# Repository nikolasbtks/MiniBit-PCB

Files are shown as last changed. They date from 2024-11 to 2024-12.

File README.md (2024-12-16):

# MiniBit-PCB

## Description

This project demonstrates a custom 2-layer PCB containing the ESP32-S3-Mini microcontroller. This board can be used for embedded development or IoT applications using multiple peripherals.

## Components

1. Microcontroller: ESP32-S3-Mini
   - 512 KB SRAM and 8 MB Flash
   - 240 MHz clock speed 
   
2. USB Connectivity:
   - USB Type-C for data and power 
   - USBLC6-2SC6 for ESD protection

3. Power Supply: AP2112K-3.3 
   - Voltage regulator for stable 3.3V output
  
4. Headers:
   - JTAG headers for debugging
   - GPIO, I2C, UART headers for external connections

## Disclaimer

This project is currently in **testing phase**. The provided documentation is shared for prototyping and learning purposes. If you choose to manufacture and use the board, please proceed with care, as it has not yet been fully validated.

## Schematic and PCB Design

The board was designed using KiCad. Files from the PCB design can be found in the **hardware** folder for board manufacture. This folder includes:

- PCB Schematic 
- PCB Layout
- Gerber files
- Assembly files

## How to Use

1. Power the board
   - Use a USB Type-C cable to power the board.
   
2. Microcontroller Programming:
   - Use Arduino IDE or any other platform to program the microcontroller.
   - Use a debugger with JTAG headers.

3. Peripheral Access
   - Use the GPIO, I2C and UART headers to connect peripherals.

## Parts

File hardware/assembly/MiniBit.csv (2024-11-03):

Reference | Value | Datasheet | Footprint | Qty | DNP
C1,C3,C4 | 0.1μF | ~ | Capacitor_SMD:C_0402_1005Metric | 3
C2 | 22μF | ~ | Capacitor_SMD:C_0805_2012Metric | 1
C5,C6 | 1μF | ~ | Capacitor_SMD:C_0402_1005Metric | 2
C7,C8 | 10nF | ~ | Capacitor_SMD:C_0402_1005Metric | 2
D1 | Red LED | ~ | LED_SMD:LED_0603_1608Metric | 1
F1 | 500mA | ~ | Fuse:Fuse_0402_1005Metric | 1
J1,J2,J3,J4 | Conn_01x04_Pin | ~ | Connector_PinHeader_2.54mm:PinHeader_1x04_P2.54mm_Vertical | 4
J5 | USB_C_Receptacle_USB2.0_16P | https://www.usb.org/sites/default/files/documents/usb_type-c.zip | Connector_USB:USB_C_Receptacle_GCT_USB4105-xx-A_16P_TopMnt_Horizontal | 1
R1 | 10k | ~ | Resistor_SMD:R_0402_1005Metric | 1
R2 | 100R | ~ | Resistor_SMD:R_0603_1608Metric | 1
R3,R4 | 5.1k | ~ | Resistor_SMD:R_0402_1005Metric | 2
R5,R6 | 22R | ~ | Resistor_SMD:R_0603_1608Metric | 2
R7,R8 | 1k5 | ~ | Resistor_SMD:R_0603_1608Metric | 2
SW1,SW2 | SW_SPST | ~ | Button_Switch_SMD:SW_SPST_B3U-1000P | 2
U1 | ESP32-S3-MINI-1 | https://www.espressif.com/sites/default/files/documentation/esp32-s3-mini-1_mini-1u_datasheet_en.pdf | RF_Module:ESP32-S2-MINI-1 | 1
U2 | USBLC6-2SC6 | https://www.st.com/resource/en/datasheet/usblc6-2.pdf | Package_TO_SOT_SMD:SOT-23-6 | 1
U3 | AP2112K-3.3 | https://www.diodes.com/assets/Datasheets/AP2112.pdf | Package_TO_SOT_SMD:SOT-23-5 | 1

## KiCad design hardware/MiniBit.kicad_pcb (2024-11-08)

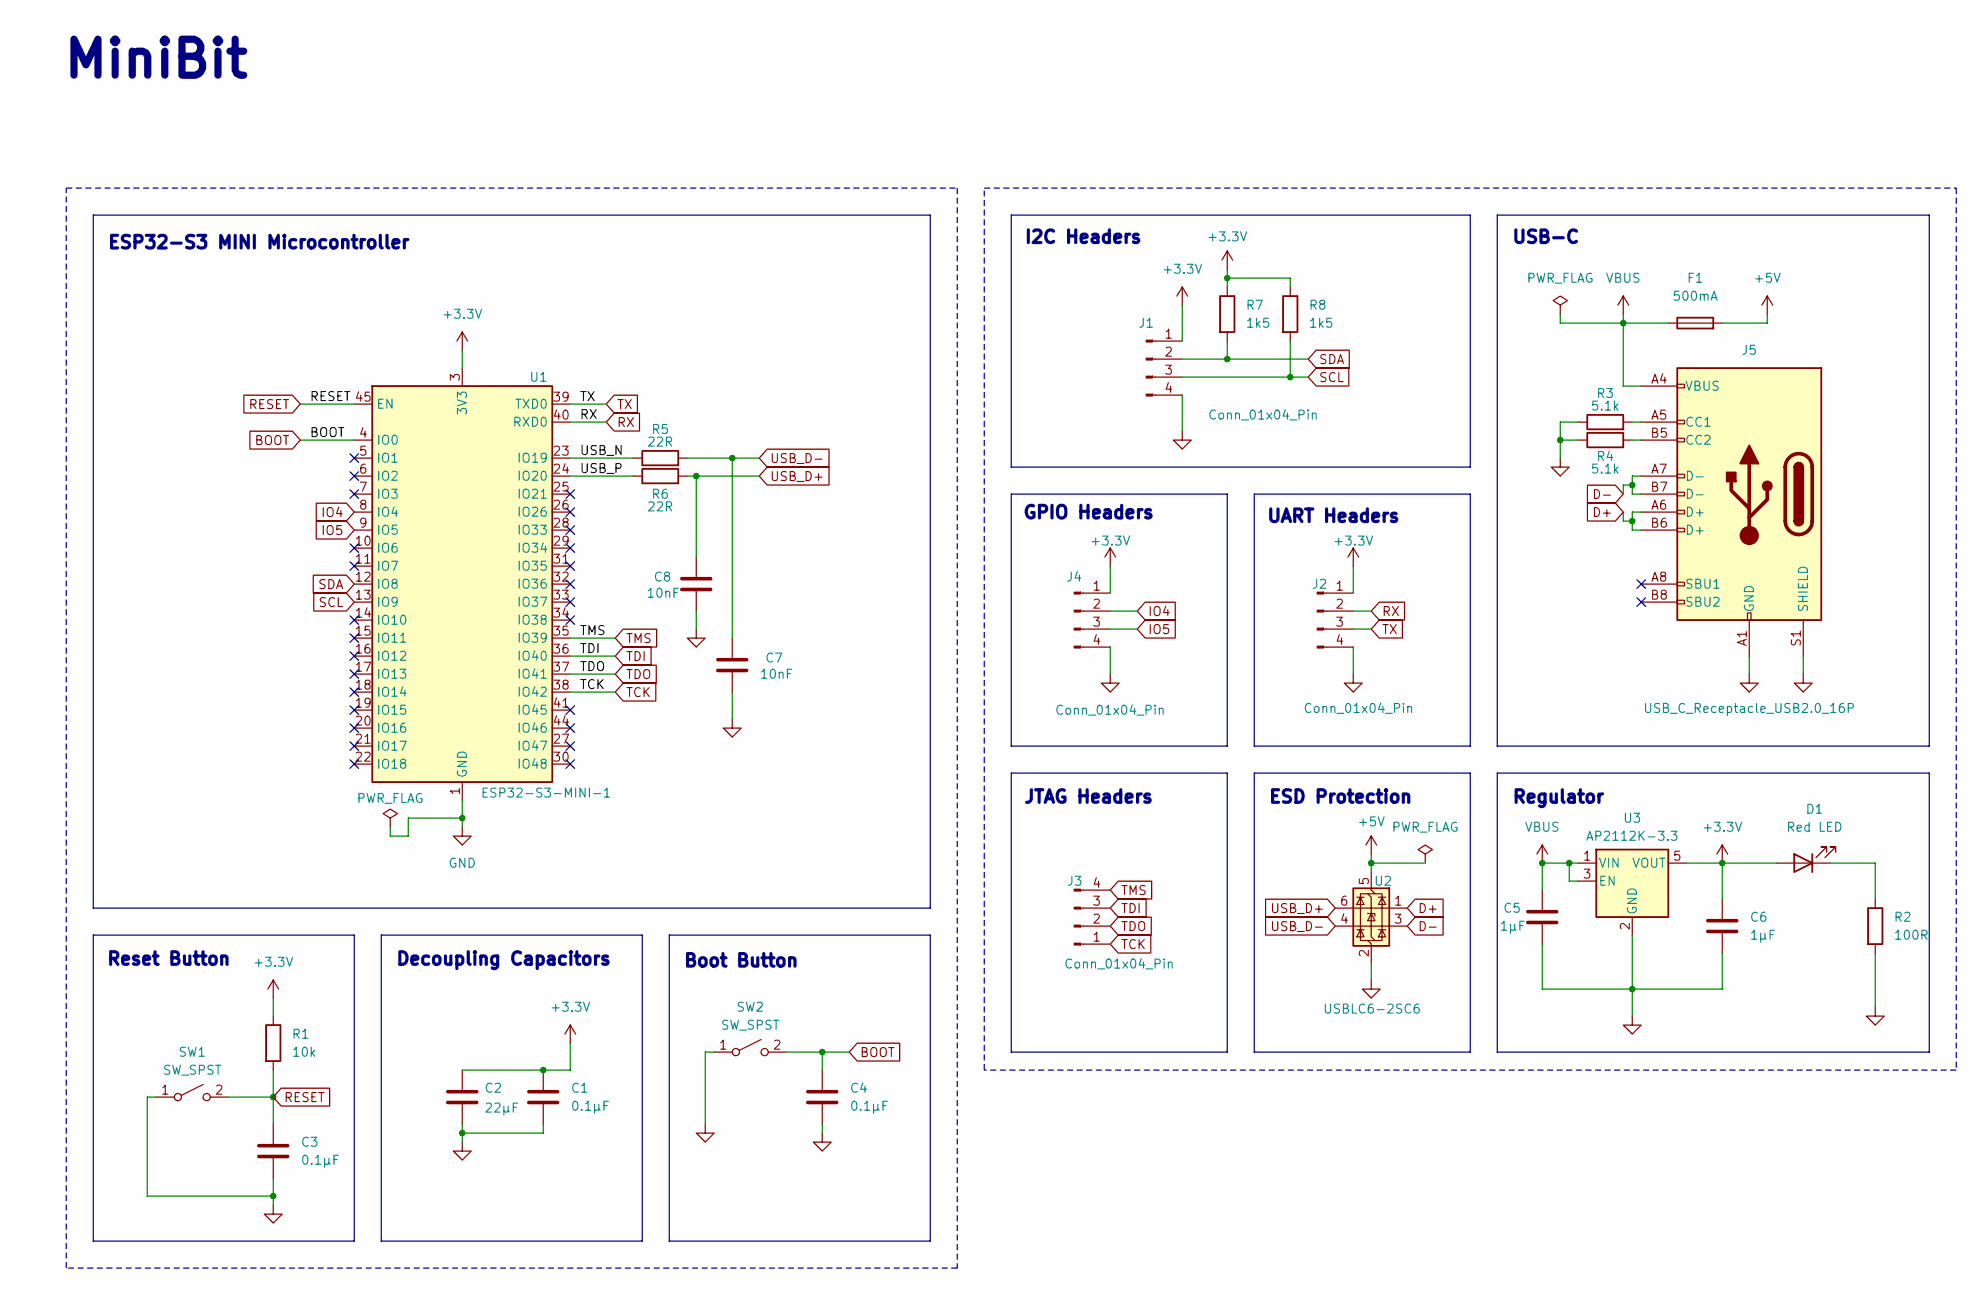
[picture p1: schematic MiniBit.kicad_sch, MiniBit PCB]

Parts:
C1, C3, C4: 0.1μF; C_0402_1005Metric
C2: 22μF; C_0805_2012Metric
C5, C6: 1μF; C_0402_1005Metric
C7, C8: 10nF; C_0402_1005Metric
D1: Red LED; LED_0603_1608Metric
F1: 500mA; Fuse_0402_1005Metric
J1, J2, J3, J4: Conn_01x04_Pin; PinHeader_1x04_P2.54mm_Vertical
J5: USB_C_Receptacle_USB2.0_16P; USB_C_Receptacle_GCT_USB4105-xx-A_16P_TopMnt_Horizontal
R1: 10k; R_0402_1005Metric
R2: 100R; R_0603_1608Metric
R3, R4: 5.1k; R_0402_1005Metric
R5, R6: 22R; R_0603_1608Metric
R7, R8: 1k5; R_0603_1608Metric
SW1, SW2: SW_SPST; SW_SPST_B3U-1000P
U1: ESP32-S3-MINI-1; ESP32-S2-MINI-1
U2: USBLC6-2SC6; SOT-23-6
U3: AP2112K-3.3; SOT-23-5

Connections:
+3.3V: C1.1, C2.1, C6.1, D1.2 (A), J1.1, J2.1, J4.1, R1.1, R7.1, R8.1, U1.3 (3V3), U3.5 (VOUT)
+5V: F1.2, U2.5 (VBUS)
/USB_N: R5.1, U1.23 (IO19)
/USB_P: R6.1, U1.24 (IO20)
BOOT: C4.1, SW2.2 (B), U1.4 (IO0)
D+: J5.A6 (D+), J5.B6 (D+), U2.1 (I/O1)
D-: J5.A7 (D-), J5.B7 (D-), U2.3 (I/O2)
GND: C1.2, C2.2, C3.2, C4.2, C5.2, C6.2, C7.2, C8.2, J1.4, J2.4, J4.4, J5.A1 (GND), J5.A12 (GND), J5.B1 (GND), J5.B12 (GND), J5.S1 (SHIELD), R2.2, R3.1, R4.1, SW1.1 (A), SW2.1 (A), U1.1 (GND), U1.2 (GND), U1.42 (GND), U1.43 (GND), U1.46 (GND), U1.47 (GND), U1.48 (GND), U1.49 (GND), U1.50 (GND), U1.51 (GND), U1.52 (GND), U1.53 (GND), U1.54 (GND), U1.55 (GND), U1.56 (GND), U1.57 (GND), U1.58 (GND), U1.59 (GND), U1.60 (GND), U1.61 (GND), U1.62 (GND), U1.63 (GND), U1.64 (GND), U1.65 (GND), U2.2 (GND), U3.2 (GND)
IO4: J4.2, U1.8 (IO4)
IO5: J4.3, U1.9 (IO5)
unnamed: D1.1 (K), R2.1
unnamed: J5.A5 (CC1), R3.2
unnamed: J5.B5 (CC2), R4.2
RESET: C3.1, R1.2, SW1.2 (B), U1.45 (EN)
RX: J2.2, U1.40 (RXD0)
SCL: J1.3, R8.2, U1.13 (IO9)
SDA: J1.2, R7.2, U1.12 (IO8)
TCK: J3.1, U1.38 (IO42)
TDI: J3.3, U1.36 (IO40)
TDO: J3.2, U1.37 (IO41)
TMS: J3.4, U1.35 (IO39)
TX: J2.3, U1.39 (TXD0)
USB_D+: C8.1, R6.2, U2.6 (I/O1)
USB_D-: C7.1, R5.2, U2.4 (I/O2)
VBUS: C5.1, F1.1, J5.A4 (VBUS), J5.A9 (VBUS), J5.B4 (VBUS), J5.B9 (VBUS), U3.1 (VIN), U3.3 (EN)

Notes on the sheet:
GPIO Headers
JTAG Headers
ESD Protection
I2C Headers
Boot Button
Reset Button
ESP32-S3 MINI Microcontroller
MiniBit
Decoupling Capacitors
USB-C
Regulator
UART Headers

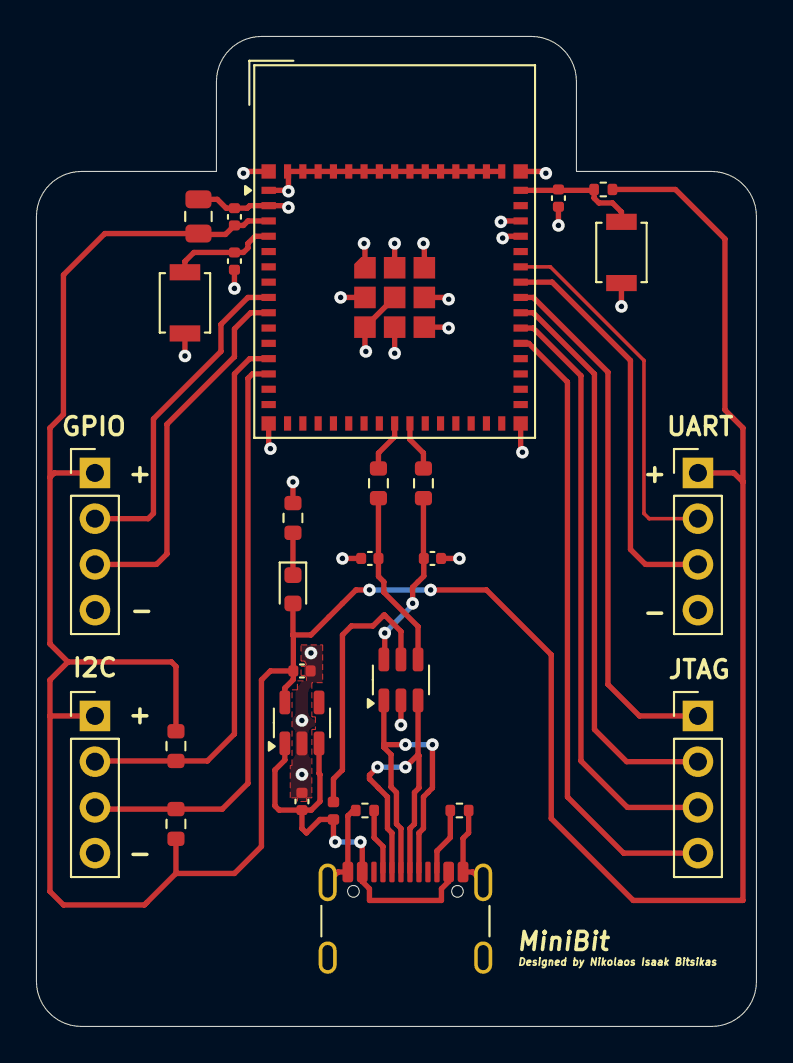
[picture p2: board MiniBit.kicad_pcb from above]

Board: 2 copper layers, 40.0 x 55.0 mm, 28 parts (0 on the bottom side), 25 nets.
